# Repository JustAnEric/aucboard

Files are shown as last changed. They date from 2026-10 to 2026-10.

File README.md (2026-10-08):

# Aucboard

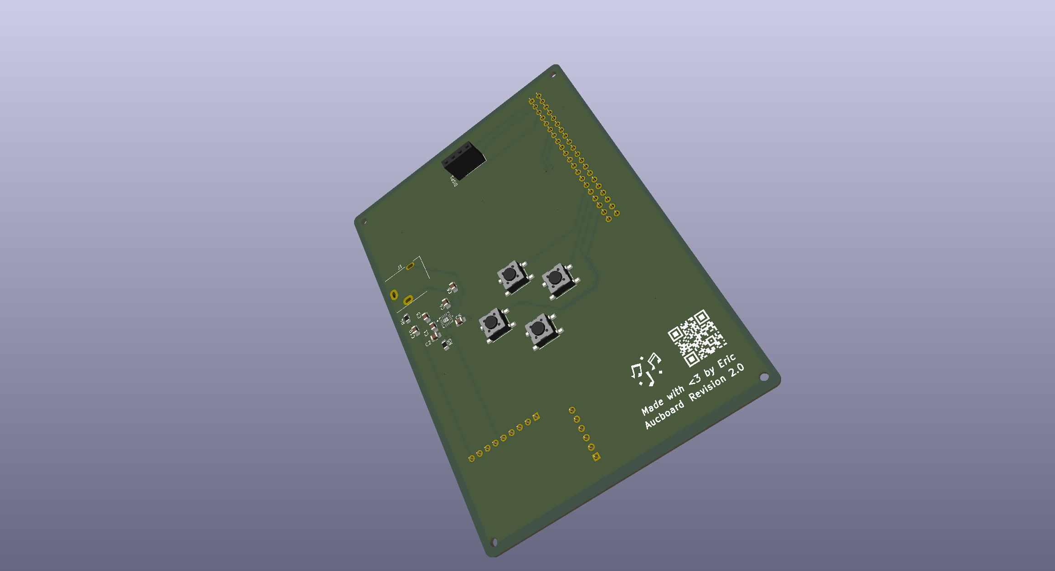
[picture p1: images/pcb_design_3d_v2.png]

Revision 2 Aucboard

> [!NOTE]
> This is my first ever hardware project involving CAD/PCB design, if there are any issues you can create one: [Create an issue](https://github.com/JustAnEric/aucboard/issues/new)

Aucboard in its design aims to provide **high fidelity**, 384KHz audio to listeners in a small package.

The hardware I am using/have used to make this project possible:

| Link | Supplier/Seller | Approx. Price |
|---|---|---|
| [Common PCM5102A DAC breakout board](https://www.amazon.com.au/VGOL-GY-PCM5102-Compatible-Ardu-inos-Raspberry/dp/B0F631QSCH) | Amazon AU | ~A$20.39 |
| [Raspberry Pi(R) Zero 2 W](https://www.raspberrypi.com/products/raspberry-pi-zero-2-w) | Hack Club (find options near you) | ~US$15.00 |
| [SSD1306 Monochrome OLED display](https://www.amazon.com.au/s?k=ssd1306) | Find options near you | ~A$15.00 - ~A$25.00 |
| Total | | A$69.89 - A$79.89 |

> [!IMPORTANT]
> ***For the perspective of Hack Club's Half Life, I have already bought the Common PCM5102A DAC breakout board, Raspberry Pi(R) Zero 2 W and the SSD1306 Monochrome OLED display myself. PCB manufacturing and fabrication costs are going to be receiving the most funding for this project.***

Tools used:

* KiCAD

The optimal fabrication solution I figured was JLCPCB, as PCBWay can charge $5-10 more per board. If you end up building this yourself, make sure to factor in those costs and whether you'd like PCBA, or manual work. For me, I'll be using PCBA.

## Board revisions

This section will go into the design process of the board.

### Rev 1

The very simplistic schematic of the board is shown below, as it was in V1 (forgetting DAC2, GPIO27, GPIO22, GPIO17, GPIO23 and AGND, I was setting up layouts for an amplifier)

* RPIZ2W1 is the header for the Raspberry Pi Zero 2 W's GPIO connections,
* GPIO5, GPIO6, GPIO13 and GPIO26 are connected to SW1-SW4,
* DISP1 is the SSD1306 OLED display module,
* DAC1 is the 6 pins the DAC provides for outputting a basic line-level signal from its preinstalled AUX jack

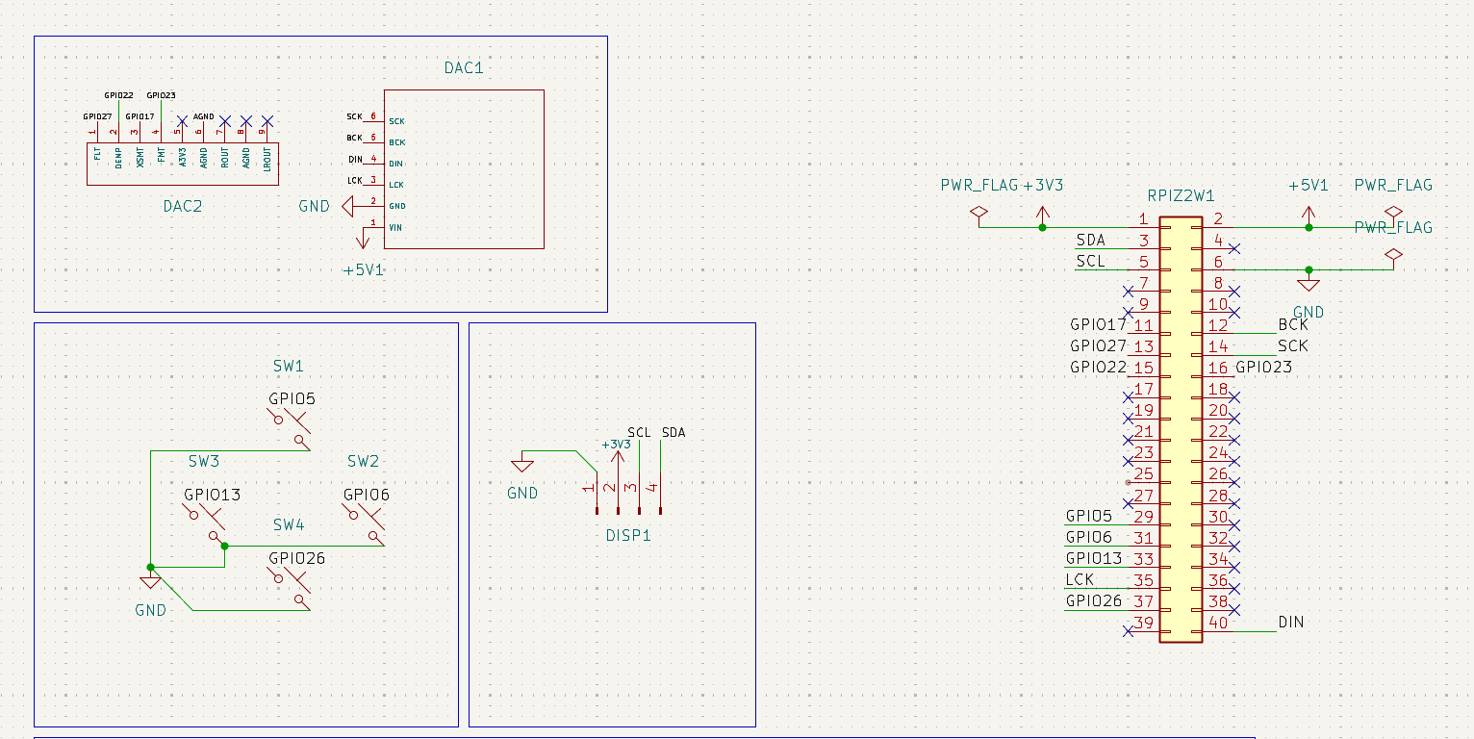
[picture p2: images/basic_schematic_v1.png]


And a bit of placement magic onto the PCB, including a ground plane with a 0.2 mm clearance, 0.3 mm thermal relief gap and solid pad connections for some shielding:

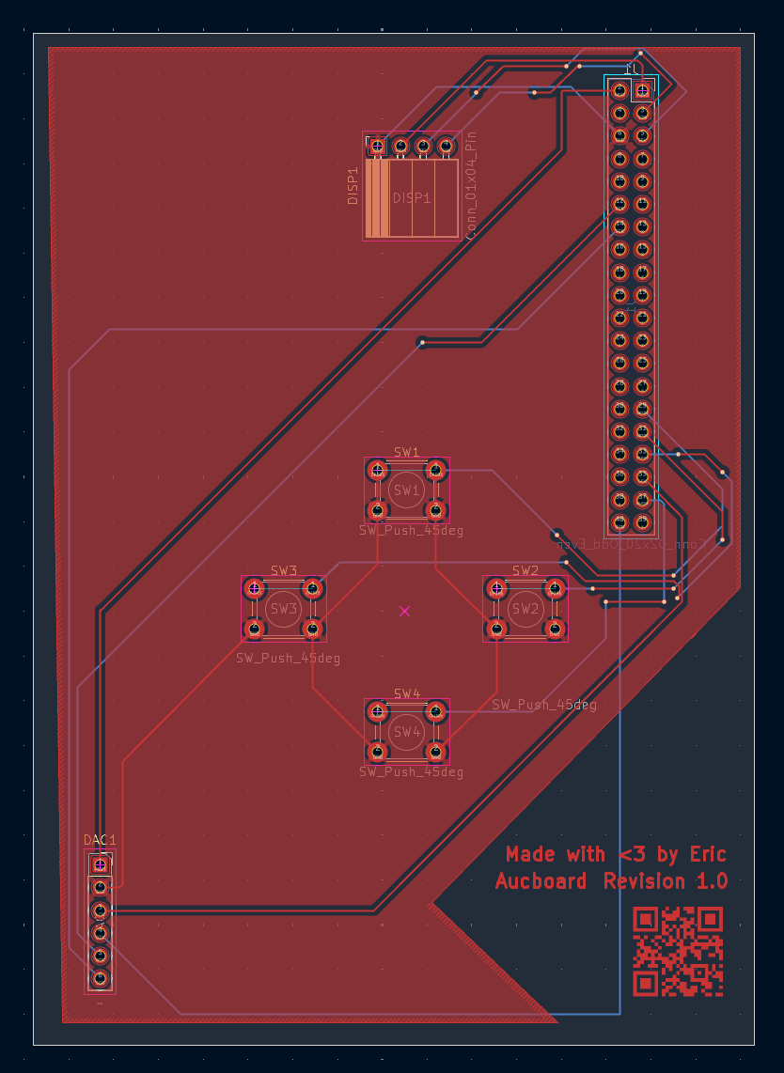
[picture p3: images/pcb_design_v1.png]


(The text and barcode was on the F.Cu layer, I didn't know this at the time and I fixed it to F.Silkscreen instead...)

So afterwards, the PCB would look like this:

<div>
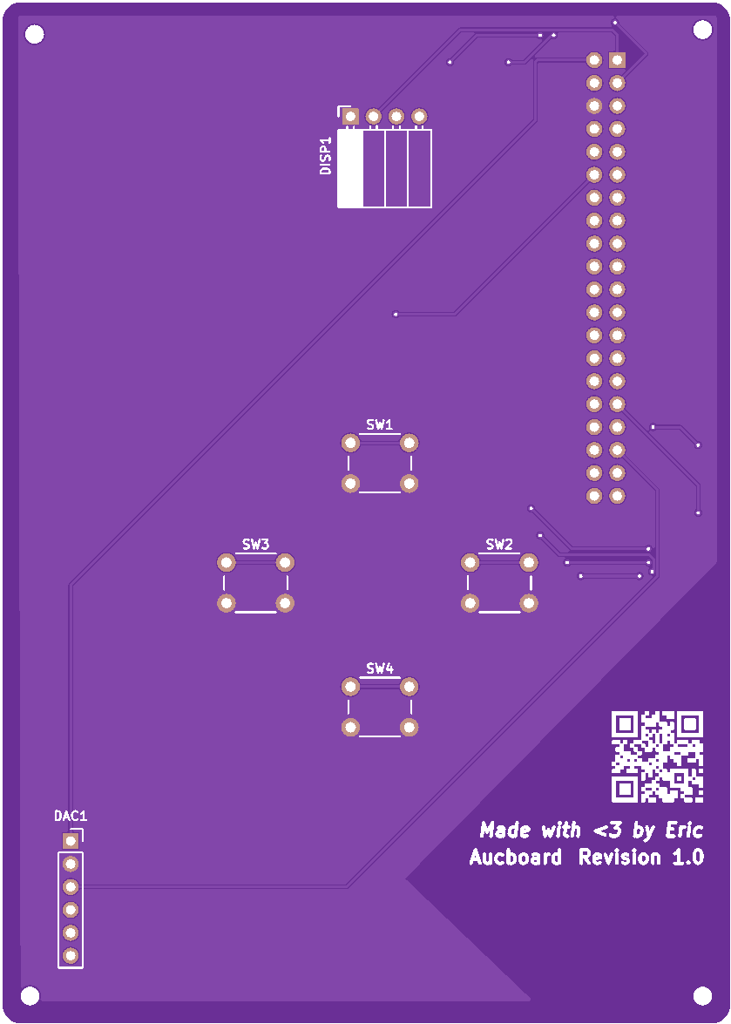
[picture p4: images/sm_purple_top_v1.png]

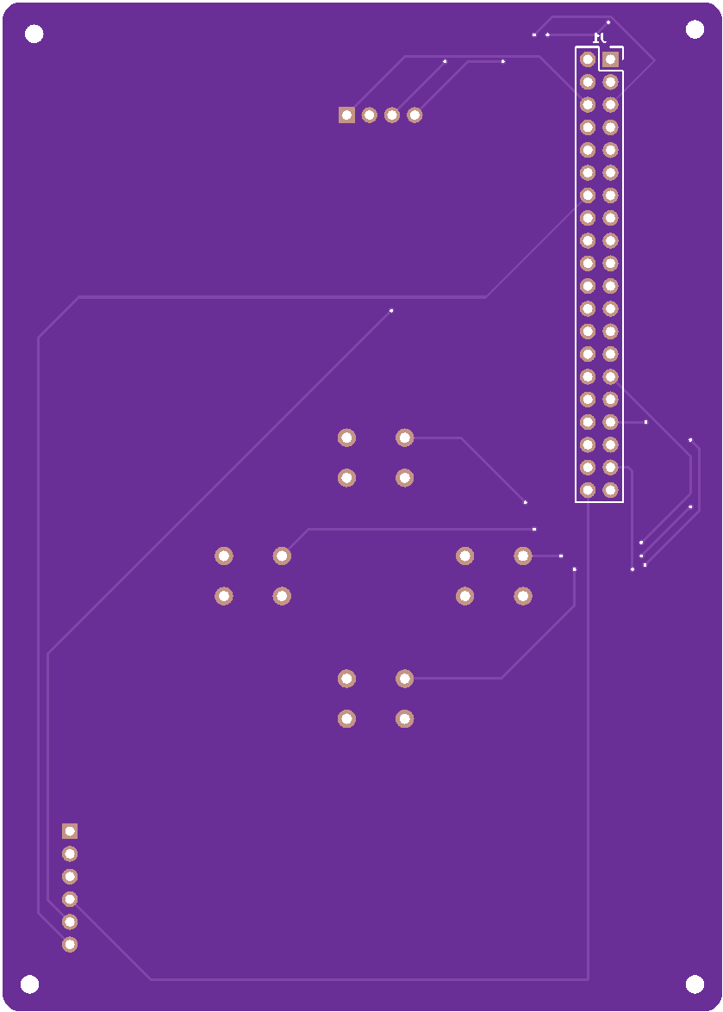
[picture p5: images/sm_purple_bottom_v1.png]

</div>

I tried my best to keep the DIN cable routed at the back and short, I wanted minimal crosstalk between the power and signal lines as is typical practice when making boards like this. Constraints required me to use a lot of vias as you can see via the dots on traces (as shown in KiCAD).

#### Flaws with this current design

This PCB has no real amplification to it. So, the line-level signal coming out from the DAC would actually fail to drive basic headphones properly unfortunately. Another design is needed, and note to self for next time:
* I should fill up as much board space as I can,
* Maybe put the amplifier next to the display,
* Optimize my traces a little more by shortening them and planning out better paths, for the amplifier this is especially important....

### Rev 2

In Revision 2.0, I added an amplifier called the MAX97220AETE+T into the mix and moved some things around. I made the buttons surface-mount so it would be way easier for me to route traces properly across the board. Additionally, there are now less vias, making the board way cleaner. This was done over 10 hours of work approximately, most of me was trying to understand the optimal circuit the PDF datasheet recommended. The amp circuit is effectively the same, but I replaced the input smoothing 0.47uF capacitors with 1uF capacitors to allow a decrease in frequency to ~15Hz rather than ~33Hz minimum.

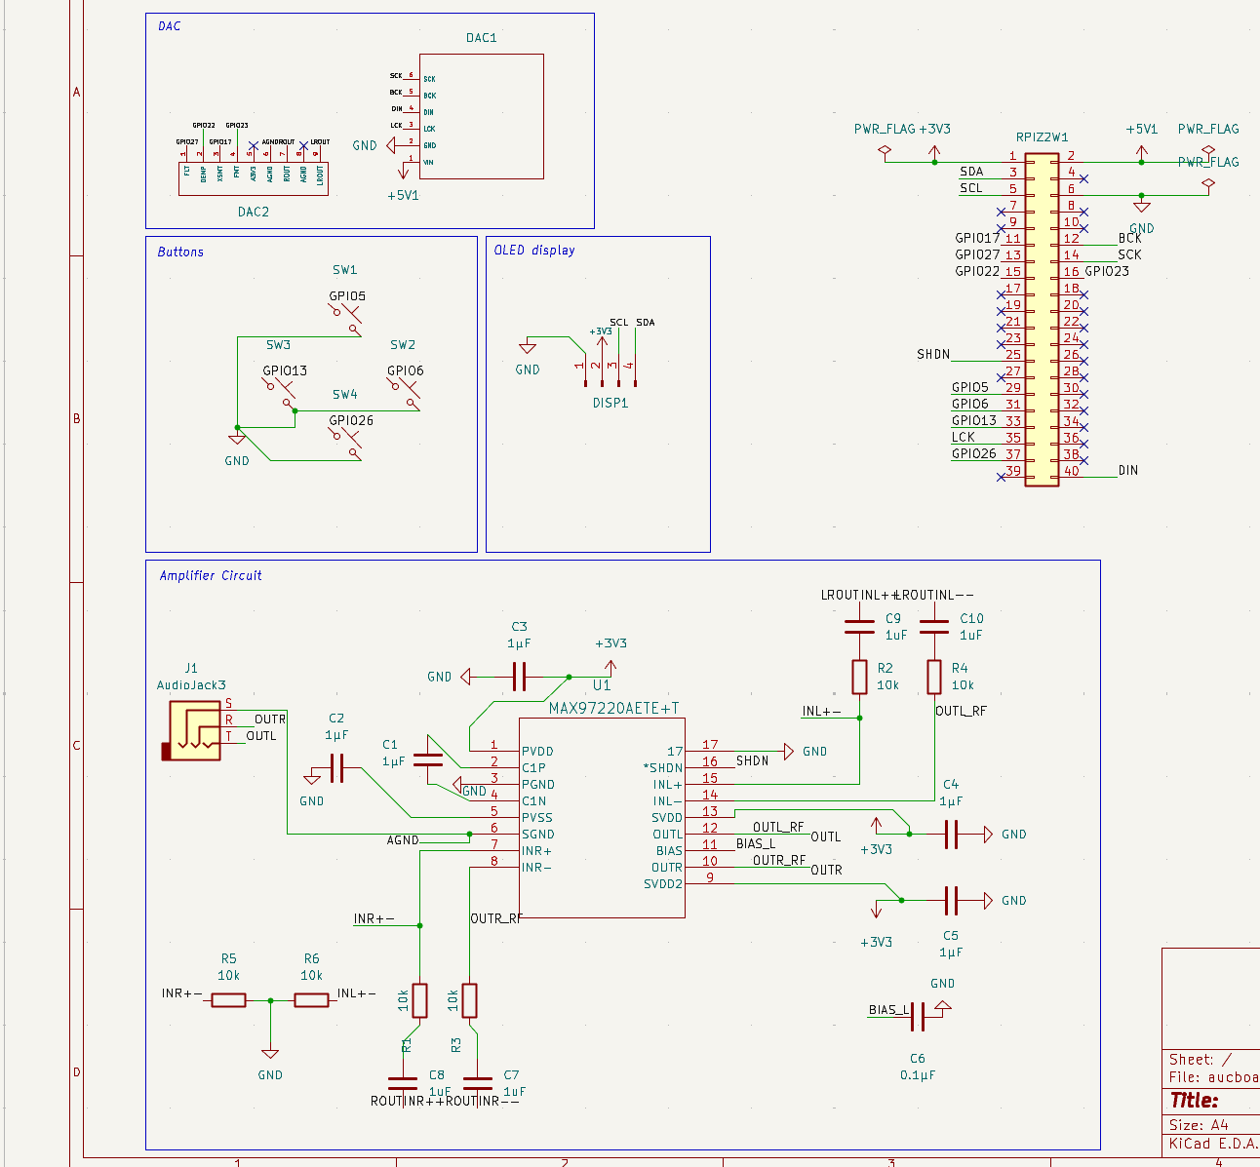
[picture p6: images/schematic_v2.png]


On the PCB, it received a full re-design, including with how components are placed. Now the DAC is flipped around to the other side and rotated, giving easier access for the amplifier circuit to work properly. There are now two (bigger) ground planes stitched to each other instead of just the one, aiming to provide better thermal spreading, better EMI shielding meaning better signal integrity, and lower impedence ground return paths.

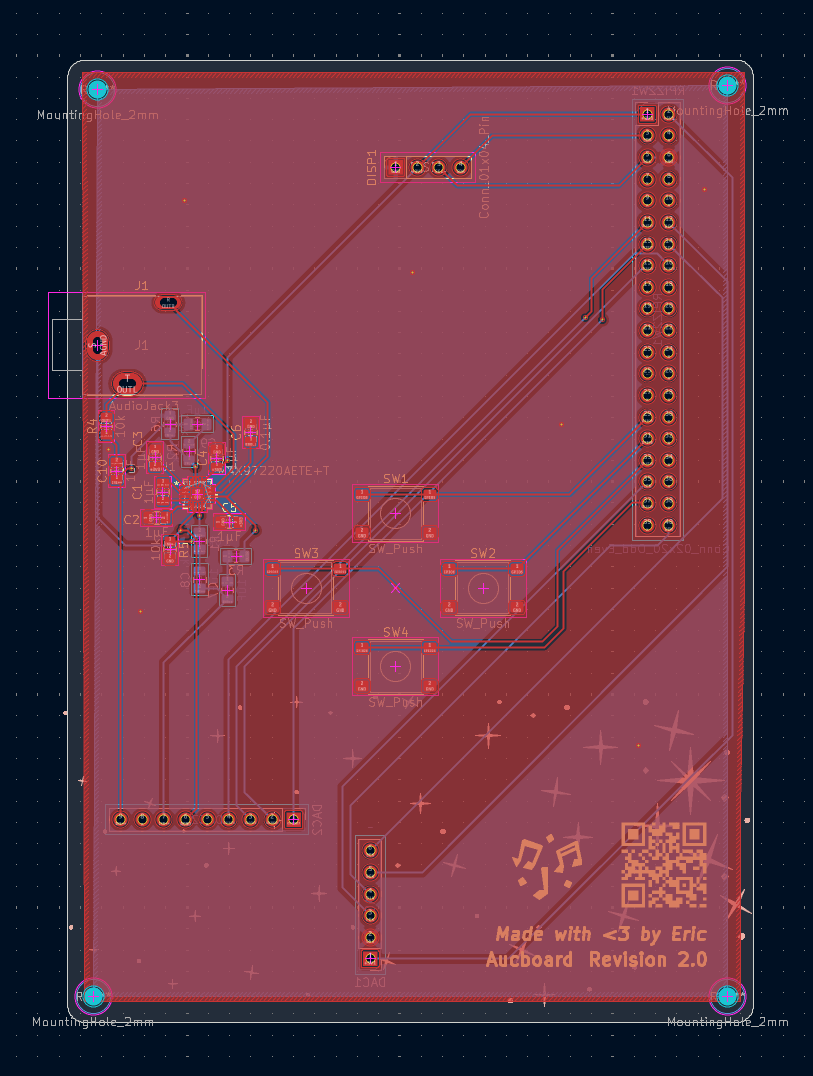
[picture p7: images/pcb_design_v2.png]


The routing spaghetti is definitely less, automatically allowing for greater reliability because not everything is very packed like Revision 1.

## Software journaling

The software implemented right now at [firmware/](firmware/) is very basic, and definitely needs greater development. Though, the greatest achievement I'm proud of is how `miniaudio` plays audio so smoothly on constrained devices. Furthermore, I can edit the audio stream *in software* rather than constantly configuring a tool like `pactl` filters.

In the first few commits, `pygame` was implemented due to its simpler `pygame.mixer`, but if I kept it like that, audio quality would've been sacrificed heavily for its simplicity. **Heavy stuttering and jitter** would have occurred for the tests directly because of Python (as the same happens with PyAudio too). Miniaudio simplifies it *way* down for Aucboard.

## Disclaimers!

This is an **ongoing project**, and I have not at all started with software yet. This README right now only shows a basic design, where everything may not be up to date as I revise.

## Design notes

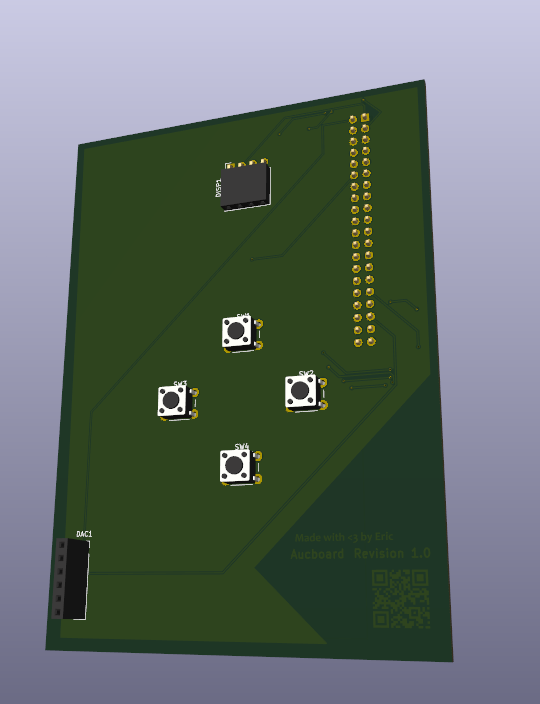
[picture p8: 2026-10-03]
images/pcb_design_3d_v1.png

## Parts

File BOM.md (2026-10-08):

# Aucboard – bill of materials

<!-- Generated by Half Life from project cmusr2gbw03s601smjny3fsbs. Edits here are overwritten on the next sync. -->
<!-- Generated: 2026-10-07T13:47:21.875Z -->

> [!NOTE]
> This parts list is mirrored from [Half Life](https://halflife.hackclub.com). Editing it here will not change the platform's copy, and the next sync overwrites this file.

| Week | Tier | Parts funding |
| --- | --- | --- |
| Warm-up | Tier 1 | $30.00 |

| Part | What it's for | Qty | Unit | Total | Vendor |
| --- | --- | --- | --- | --- | --- |
| [128x64 OLED display](https://core-electronics.com.au/white-i2c-oled-display-ssd1306.html) | For displaying things like song status on a screen | 1 | $4.55 | $4.55 | [Core Electronics Australia](https://core-electronics.com.au/white-i2c-oled-display-ssd1306.html) |
| **Parts subtotal** | — | — | — | **$4.55** | — |
| **Tax & shipping** | — | — | — | **$0.65** | — |
| **Total** | — | — | — | **$5.20** | — |

$24.80 left of the tier's funding.

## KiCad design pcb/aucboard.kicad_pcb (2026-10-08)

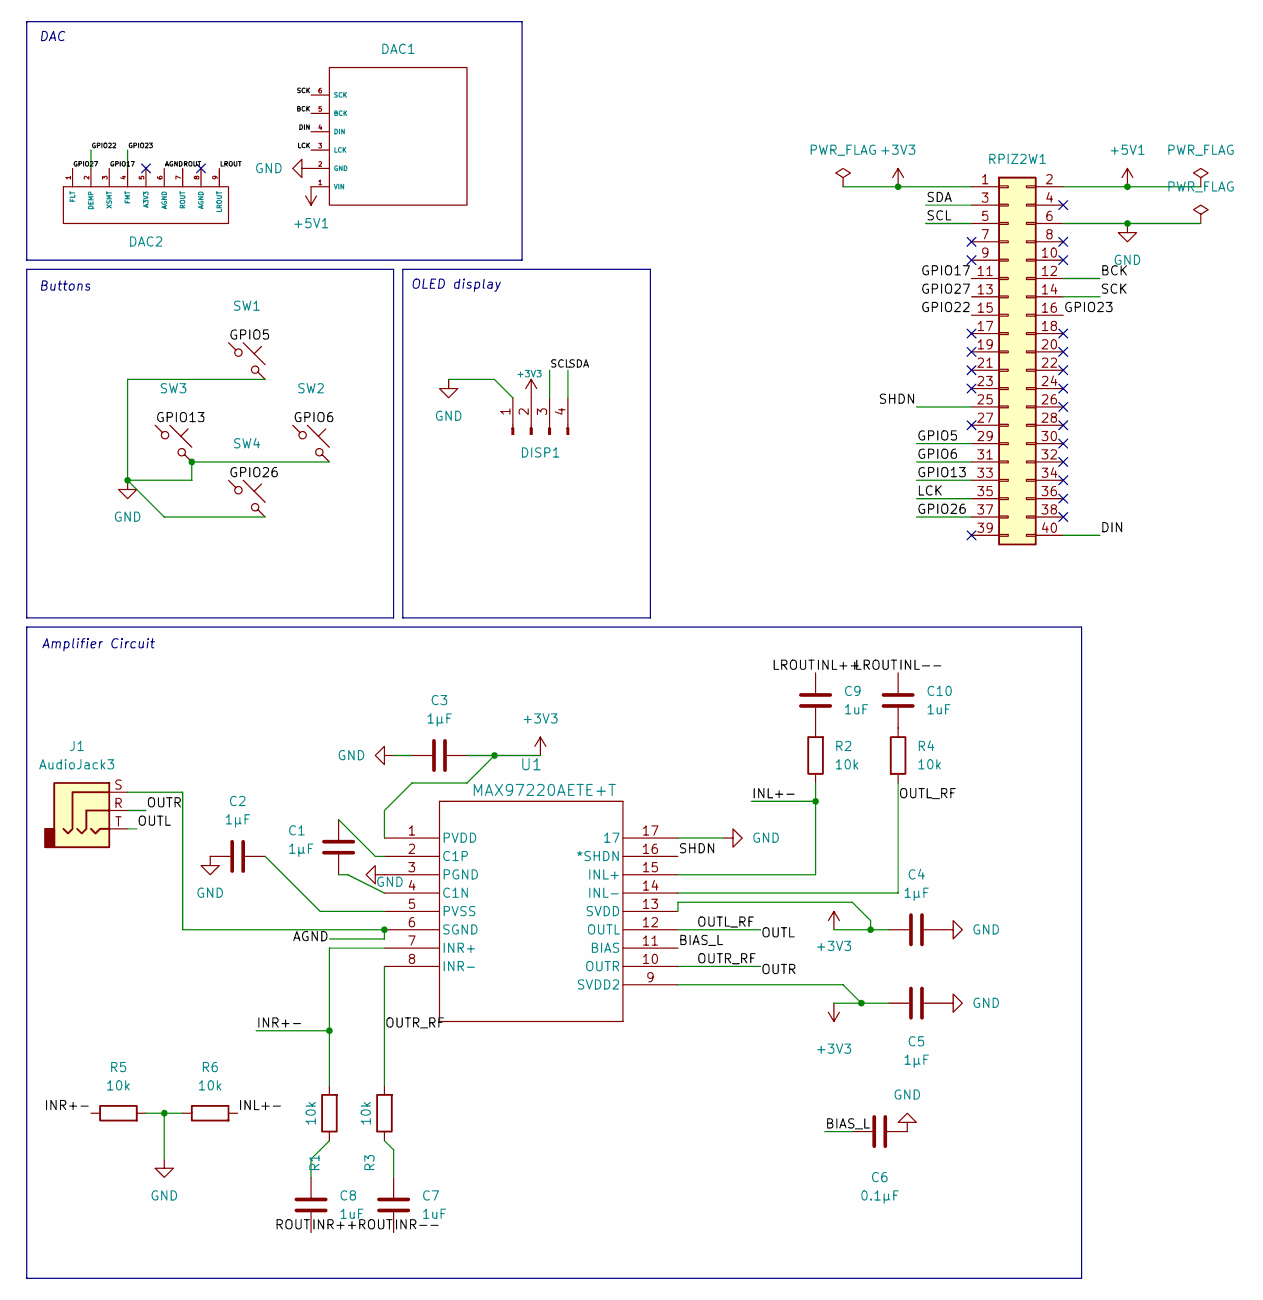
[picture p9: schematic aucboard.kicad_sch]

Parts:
C1, C2, C3, C4, C5: 1µF; C_0805_2012Metric_Pad1.18x1.45mm_HandSolder
C6: 0.1µF; C_0805_2012Metric_Pad1.18x1.45mm_HandSolder
C7, C8, C9, C10: 1uF; C_0805_2012Metric_Pad1.18x1.45mm_HandSolder
DAC1: PinSocket_1x06_P2.54mm_Vertical
DAC2: PinSocket_1x09_P2.54mm_Vertical
DISP1: Conn_01x04_Pin; PinSocket_1x04_P2.54mm_Vertical
J1: AudioJack3; Jack_3.5mm_CUI_SJ1-3513N_Horizontal
R1, R2, R3, R4, R5, R6: 10k; R_0805_2012Metric_Pad1.20x1.40mm_HandSolder
RPIZ2W1: Conn_02x20_Odd_Even; PinSocket_2x20_P2.54mm_Vertical
SW1, SW2, SW3, SW4: SW_Push; SW_SPST_PTS645Sx43SMTR92
U1: MAX97220AETE+T; 21-0136I_T1633-4_MXM

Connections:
+3V3: C3.2, C4.1, C5.2, DISP1.2, RPIZ2W1.1, U1.1 (PVDD), U1.9 (SVDD2), U1.13 (SVDD)
+5V1: DAC1.1 (VIN), RPIZ2W1.2
/AGND: DAC2.6 (AGND), J1.S, U1.6 (SGND)
/BCK: DAC1.5 (BCK), RPIZ2W1.12
/BIAS_L: C6.1, U1.11 (BIAS)
/DIN: DAC1.4 (DIN), RPIZ2W1.40
/GPIO5: RPIZ2W1.29, SW1.1
/GPIO6: RPIZ2W1.31, SW2.1
/GPIO13: RPIZ2W1.33, SW3.1
/GPIO17: DAC2.3 (XSMT), RPIZ2W1.11
/GPIO22: DAC2.2 (DEMP), RPIZ2W1.15
/GPIO23: DAC2.4 (FMT), RPIZ2W1.16
/GPIO26: RPIZ2W1.37, SW4.1
/GPIO27: DAC2.1 (FLT), RPIZ2W1.13
/INL++: C9.1, C10.1, DAC2.9 (LROUT)
/INL+-: R2.1, R6.2, U1.15 (INL+)
/INR++: C7.2, C8.2, DAC2.7 (ROUT)
/INR+-: R1.2, R5.1, U1.7 (INR+)
/LCK: DAC1.3 (LCK), RPIZ2W1.35
/OUTL: J1.T, R4.2, U1.12 (OUTL), U1.14 (INL-)
/OUTR: J1.R, R3.2, U1.8 (INR-), U1.10 (OUTR)
/SCK: DAC1.6 (SCK), RPIZ2W1.14
/SCL: DISP1.3, RPIZ2W1.5
/SDA: DISP1.4, RPIZ2W1.3
GND: C2.1, C3.1, C4.2, C5.1, C6.2, DAC1.2 (GND), DISP1.1, R5.2, R6.1, RPIZ2W1.6, SW1.2, SW2.2, SW3.2, SW4.2, U1.3 (PGND), U1.17
unnamed: C7.1, R3.1
unnamed: C8.1, R1.1
unnamed: C9.2, R2.2
unnamed: C10.2, R4.1
unnamed: C1.2, U1.4 (C1N)
unnamed: C1.1, U1.2 (C1P)
unnamed: C2.2, U1.5 (PVSS)

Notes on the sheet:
Amplifier Circuit
DAC
OLED display
Buttons

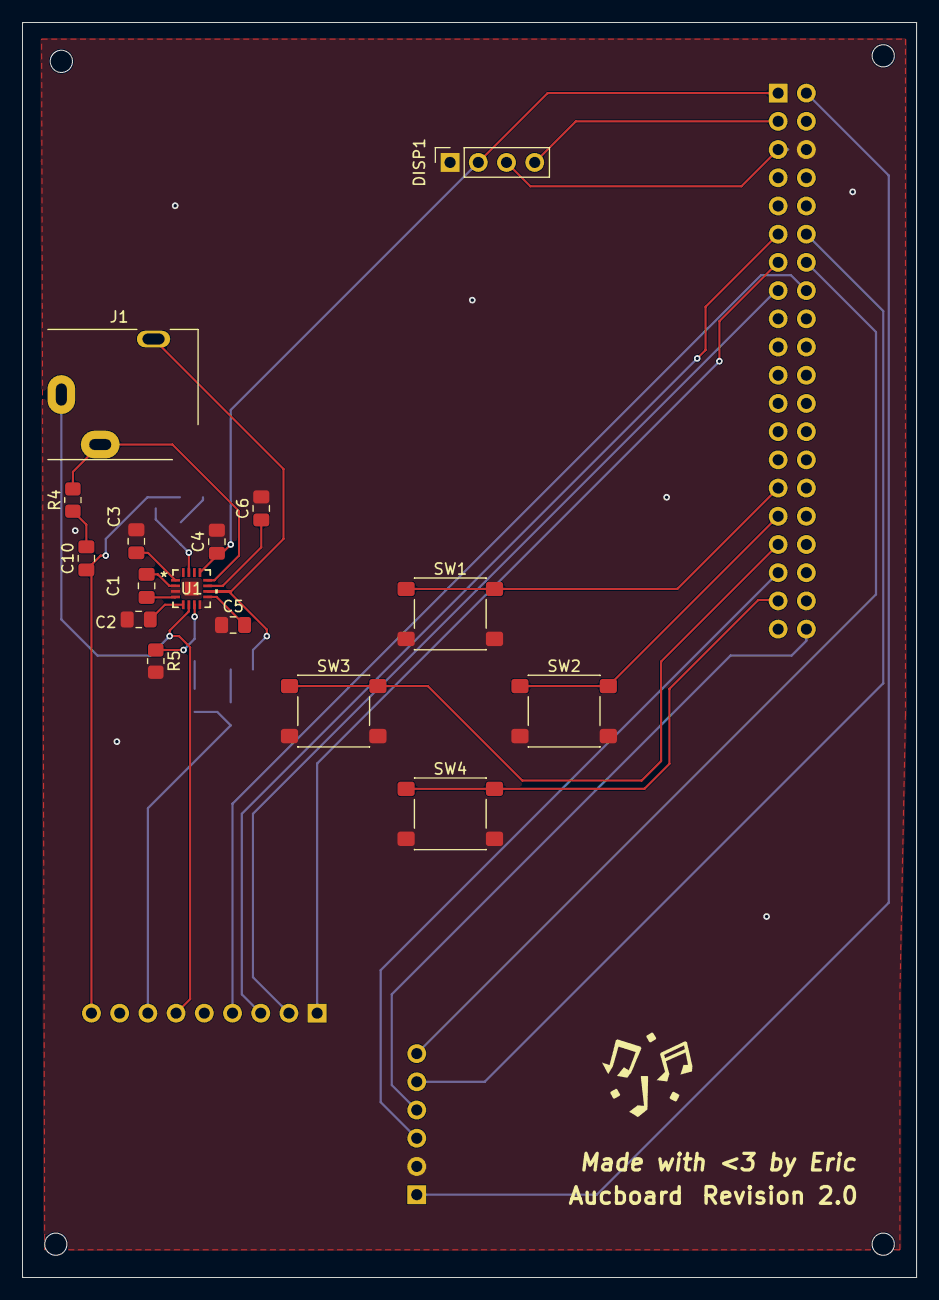
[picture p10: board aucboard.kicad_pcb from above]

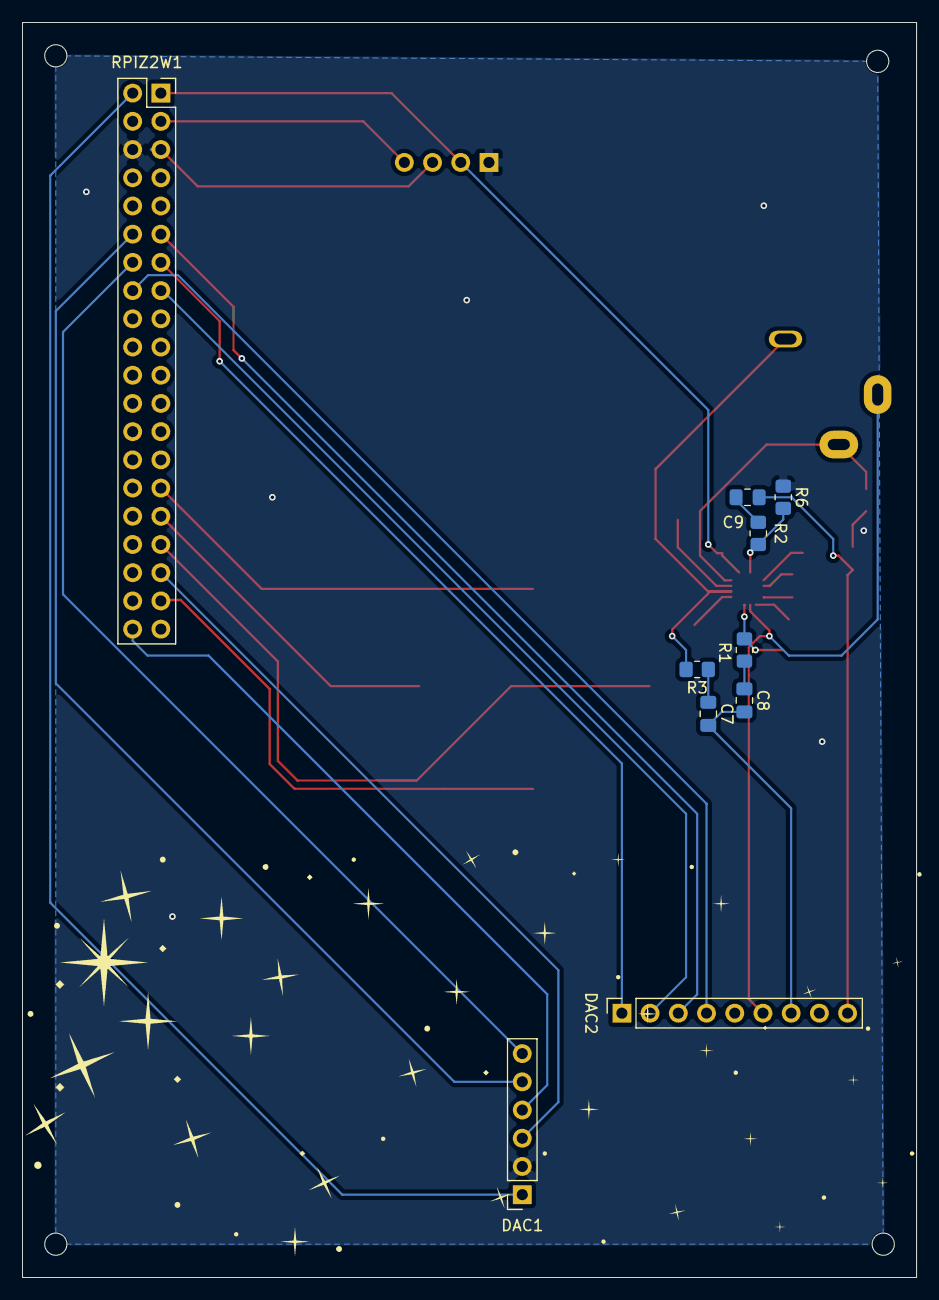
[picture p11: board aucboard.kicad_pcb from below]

Board: 2 copper layers, 80.5 x 113.0 mm, 26 parts (10 on the bottom side), 32 nets.

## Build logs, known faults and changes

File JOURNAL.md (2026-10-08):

# Aucboard – devlog

<!-- Generated by Half Life from project cmusr2gbw03s601smjny3fsbs. Edits here are overwritten on the next sync. -->
<!-- Generated: 2026-10-03T19:45:15.449Z -->

> [!NOTE]
> This devlog is mirrored from [Half Life](https://halflife.hackclub.com). Editing it here will not change the platform's copy, and the next sync overwrites this file.

> Aucboard aims to provide high fidelity, 384KHz audio to listeners in a portable device form-factor

| Week | Tier | Hours logged | Entries |
| --- | --- | --- | --- |
| Warm-up | Tier 1 | 8h | 1 |

## Contents

1. [2026-10-03 – I made silly designs for the PCB and overall schematic in this session, with help from Claude for creation of the symbol DAC1! I used net labels to handle wiring on the PCB later instead of on the sch](#2026-10-03-i-made-silly-designs-for-the-pcb-and-overall-sche)

## Design

### 2026-10-03 – I made silly designs for the PCB and overall schematic in this session, with help from Claude for creation of the symbol DAC1! I used net labels to handle wiring on the PCB later instead of on the sch

**8h**

I made silly designs for the PCB and overall schematic in this session, with help from Claude for creation of the symbol DAC1! I used net labels to handle wiring on the PCB later instead of on the schematic. Typical KiCAD starter here...



Some issues I ran into today was with no connect symbols giving me a lot of errors in DRC, as can be seen here:



They even gave a lot of grief when I was trying to REMOVE them until I realized you could just long click and have a context menu that you select the no connect symbol in -_- pfft

Making the traces was harder than expected, it looks like total wire spaghetti so I think I need to refine it next time:



I got a ground plane too made out of copper with 6 sides to provide some extra shielding for the audio circuitry (the red part you see with the traces outlined):



I also had to fix up the text because I stupidly put it on the F.Cu layer, now it's on the F.Silkscreen layer instead! Very beautiful font work "KiCad Font" (it wouldn't let me choose another, kept complaining about thickness :P)



I didn't know I had to create this project first on Half Life so... def downloading Lapse next time

I also put some mounting holes with a 2 mm size (M2 I think???) This is also when I realized the pinout with my symbol was wrong and I had to rotate the DAC connector and retrace it up 🥲





The design looks better than I would've ever expected though from a first circuit,



I'm ecstatic and I'll keep revising this in PCB week (oct 5). The next few hours I'll be doing basic software for the Pi Zero 2 W so I'm ready for when that time comes.

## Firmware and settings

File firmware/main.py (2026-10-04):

from gpiozero import Button, OutputDevice
from gpiozero.pins.native import NativeFactory
from player import Player

from luma.core.interface.serial import spi, i2c
from luma.core.render import ImageDraw, canvas
from luma.oled.device import ssd1306, device

import os, pathlib, sys, logging, shutil, time, threading, socket, json

BASE_DIR = pathlib.Path(os.path.dirname(__file__))

class PlayerState:
    def __init__(self):
        self.player = Player()
        self.last_tick = 0
        self.queue = []
        self.queue_index = 0

        self._track_ended = threading.Event()

        @self.player.on_end
        def on_player_end():
            print('track ended')

            self._track_ended.set()

    @property
    def playing(self):
        return self.player.is_playing

    @playing.setter
    def playing(self, value: bool):
        if value == True:
            self.player.resume()
        elif value == False:
            self.player.pause()
        else:
            logger.warning("Unintentional set on PlayerState.playing? (not a bool value!)")

    @property
    def position(self):
        return self.player.current_track.current_time

    @position.setter
    def position(self, value: float):
        self.player.current_track.current_time = value

    @property
    def duration(self):
        return self.player.duration

    def advance_track(self):
        if not self.queue:
            return

        if self.queue_index == len(self.queue) - 1:
            self.queue_index = 0
        else:
            self.queue_index += 1
        self.position = 0.0
        self.playing = True

    def rewind_track(self):
        if not self.queue:
            return

        if self.queue_index == 0:
            self.queue_index = len(self.queue) - 1
        else:
            self.queue_index -= 1
        self.position = 0.0

def update_playback(state: PlayerState, delta):
    if not state.playing:
        return
    state.position += delta
    #if state.position >= state.duration:
    #    state.advance_track()
    #    state.playing = True # set new state

def enum_tracks(dir="./music"):
    for dirp,dirn,filn in os.walk(dir):
        for f in filn:
            fullpath = os.path.join(dirp, f)
            froot,fext = os.path.splitext(f)
            if fext.lower() in [".mp3",".flac",".mp4"]:
                print("Found:",fullpath)
                state.queue.append({ "path": fullpath, "filename": f, "metadata": {} })

def update_boot(sock, percent, status):
    msg = json.dumps({"percent": percent, "status": status}) + "\n"
    sock.sendall(msg.encode())

def main(device: device, state: PlayerState, boot_s: socket.socket):
    # mainloop
    logger.info("Mainloop started")

    update_boot(boot_s, 100, "Ready!")
    boot_s.close()

    enum_tracks(BASE_DIR / "music")

    state.player.play(state.queue[state.queue_index]['path'])

    while True:
        with canvas(device) as cv:
            now = time.monotonic()
            delta = now - state.last_tick
            state.last_tick = now
            if state._track_ended.is_set():
                state._track_ended.clear()
                state.advance_track()
                state.player.play(state.queue[state.queue_index]['path'])
            else:
                update_playback(state, delta)

        time.sleep(0.05)

if __name__ == "__main__":
    #imports for modules
    from modules.web import WebApp

    logging.basicConfig()
    logger = logging.getLogger("aucboard")

    if not os.path.exists("/tmp/aucboard_boot.sock"):
        print("Aucboard can only run on boot! You can't run this script directly.")
        sys.exit(2)

    s = socket.socket(socket.AF_UNIX, socket.SOCK_STREAM)
    s.connect("/tmp/aucboard_boot.sock")
    update_boot(s, 25, "Starting audio...")

    logger.info("Aucboard is starting...")

    if not os.path.exists(BASE_DIR / "music"):
        logger.warning("Aucboard music directory was not found, creating...")
        os.makedirs(BASE_DIR / "music", exist_ok=True)

    #gpio
    TOP_BUTTON = Button("BOARD29")
    RIGHT_BUTTON = Button("BOARD31")
    LEFT_BUTTON = Button("BOARD33")
    BOTTOM_BUTTON = Button("BOARD37")

    FLT_DAC = OutputDevice("BOARD13") # or gp 27 
    DEMP_DAC = OutputDevice("BOARD15") # or gp 22
    XSMT_DAC = OutputDevice("BOARD11") # or gp 17 | softmute
    FMT_DAC = OutputDevice("BOARD16") # or gp 23

    #display
    DISP1_PORT = 1
    DISP1_ADDRESS = 0x3c
    DISP1 = ssd1306(i2c(port=DISP1_PORT, address=DISP1_ADDRESS))

    state = PlayerState()

    web = WebApp(state)
    web.run_in_thread()

    main(
        DISP1, 
        state,
        s
    )

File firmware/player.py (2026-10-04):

from tinytag import TinyTag
from modules.equalizer import EQBand

import dataclasses, time, subprocess, threading, miniaudio, array, numpy as np, os

@dataclasses.dataclass
class TrackState:
    name: str = "Untitled Track"
    album_name: str = "Untitled Album"
    file_name: str = ""
    duration_s: float = 0.0
    current_time: float = 0.0
    bitrate: float = 0.0
    volume: int = 100
    quality_str: str = "0 Hz"

class Player:
    def __init__(self):
        self.current_track = TrackState()
        self.end_event_hooks = []
        self.is_running = True
        self.is_paused = False
        self.eq_bands = [
            EQBand(32), EQBand(64),
            EQBand(125),EQBand(250),
            EQBand(500),EQBand(1000),
            EQBand(2000),EQBand(4000),
            EQBand(8000),EQBand(16000)
        ]

        self.device = miniaudio.PlaybackDevice(output_format=miniaudio.SampleFormat.SIGNED32)
        self.audio = None

        self.track_ended = False # mainloop flag

        for band in self.eq_bands:
            band.setup(self.device.sample_rate, self.device.nchannels)
        
    def on_end(self, func):
        self.end_event_hooks.append(func)
    
    @property
    def is_playing(self):
        if not self.audio:
            return False
        if not self.is_paused:
            return True
        return False

    def play(self, fn: str | None = None):
        if fn:
            self.current_track.file_name = fn

        if self.audio:
            self.device.stop()

        td = self.get_audio_duration_and_bitrate(fn or self.current_track.file_name)
        self.current_track.duration_s = td[0]
        self.current_track.bitrate = td[1]
        ttd = TinyTag.get(fn or self.current_track.file_name)
        self.current_track.album_name = ttd.album or "Untitled Album"
        self.current_track.name = ttd.title or "Untitled Track"

        self.audio = self.stream_audio_with_callback(fn or self.current_track.file_name, self._on_track_end, self.device.nchannels, self.device.sample_rate)
        next(self.audio)
        self.device.start(self.audio)

    def pause(self):
        self.is_paused = True

    def resume(self):
        self.is_paused = False

    def volume(self, value: int | None = None):
        if value is not None:
            self.current_track.volume = value
        else:
            return self.current_track.volume

    @property
    def duration(self):
        return self.current_track.duration_s

    def get_audio_duration_and_bitrate(self, file_path):
        cmd = [
            'ffprobe',
            '-i', file_path,
            '-show_entries', 'format=duration:stream=bit_rate,sample_fmt',
            '-of', 'default=noprint_wrappers=1:nokey=1'
        ]
        
        try:
            result = subprocess.run(cmd, capture_output=True, text=True, check=True)
            
            lines = result.stdout.splitlines()
            duration = float(lines[-1])

            quality = lines[0].strip()
            bitrate_raw = lines[1].strip()
            duration = float(lines[2].strip())
            
            # Calculate bitrate manually instead
            if bitrate_raw == "N/A" or not bitrate_raw.isdigit():
                file_size_bytes = os.path.getsize(file_path)
                # Bits per second = bytes * 8 / duration
                # Kilobits per second (kbps) = bits per second / 1000
                bitrate = int((file_size_bytes * 8) / (duration * 1000))
            else:
                bitrate = int(bitrate_raw)
            
            return duration, bitrate, quality
        except subprocess.CalledProcessError as e:
            print(f"Error: {e}")
            return None, None, None

    def stream_audio_with_callback(self, fp, callback, nchannels, sample_rate):
        source_stream = miniaudio.stream_file(fp, output_format=miniaudio.SampleFormat.SIGNED32, nchannels=nchannels, sample_rate=sample_rate)
        required_frames = yield b""

        while True:
            try:
                if self.is_paused:
                    silence = b"\x00" * (required_frames * 2 * 4) 
                    required_frames = yield silence
                    continue

                data = source_stream.send(required_frames)
                if not data:
                    break

                samples = np.frombuffer(data, dtype=np.float32).copy()
                samples = samples.reshape(-1, nchannels)

                for band in self.eq_bands:
                    samples = band.process(samples)

                curr_vol = self.volume() / 100.00
                if curr_vol != 1.0:
                    samples *= curr_vol
                    np.clip(samples, -1.0, 1.0, out=samples)

                data = samples.astype(np.float32).tobytes()
                required_frames = yield data

            except StopIteration:
                break

        callback()

    def _on_track_end(self):
        for i in self.end_event_hooks:
            i()

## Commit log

2026-10-03 Initial commit, upload gerber files and base README
    [aucboard-B_Cu.gbr, aucboard-B_Mask.gbr, aucboard-B_Paste.gbr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]
2026-10-03 Add base hardware costs and README circuit diagrams
2026-10-03 Establish GPIO pins from board layout and add more packages
2026-10-04 Fix queue bug, (main.update_playback), remedy bitrate bug (player.Player.get_audio_duration_and_bitrate)
    [main.py, player.py]
2026-10-04 Make web module and implement, improved safety of GPIO/i2C/SPI devices and after boot
2026-10-05 Upload gerber files
    [aucboard-B_Cu.gbr, aucboard-B_Mask.gbr, aucboard-B_Paste.gbr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]
2026-10-06 Add i2c-dev.target dependency to boot service
2026-10-08 Update repo README with Revision 2 and release Revision 2 files
    [aucboard-B_Cu.gbr, aucboard-B_Mask.gbr, aucboard-B_Paste.gbr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]
